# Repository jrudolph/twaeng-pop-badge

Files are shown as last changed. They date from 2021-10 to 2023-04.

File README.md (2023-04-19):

# Twäng POP! Badge

These are [KiCad](https://www.kicad.org/) sources from which the [Twäng](https://twaeng.de) [pop!](https://twaeng.de/musik/pop) badge was produced. This
is basically version 2 of the blinky sign described [on the blog](https://blog.virtual-void.net/2022/06/17/creating-a-blinky-sign-for-twaeng/).

The updated firmware can be built from the `pop-badge` branch of the [firmware repository](https://github.com/jrudolph/twaeng-pop-sign/tree/pop-badge).

## Schematics

The idea was to keep the basic original design based around a RPi Pico and WS2812b LEDs. For space and
cost reasons the amount of WS2812 LEDs was reduced to 25 and the smaller variant was chosen.

Additionally, 50 simple white LEDs were
added as a frame for the sign. These LEDs can not be controlled individually but only as the whole set. The brightness can be set by choosing appropriate PWM settings. 50 LEDs could consume 1A of
current which is a lot and cannot be sourced from a microcontroller pin directly. Since this was my first
electronics design, I was not totally certain how to set this up properly, so I went with a design, where I put both an NPN-transistor and an N-channel MOSFET on the board configurable via solder
jumpers. (It wasn't clear to me how much current the NPN transistor would really need to switch on all those 50 LEDs. The current gain might be enough to drive those but I wasn't sure what it would mean under PWM and under how much strain it would put the output pin of the Pico.)

I also put a debug header on the board for easy testing of components without requiring to
immediately solder the RPi Pico.

The Pico itself is soldered to the back using its castellated edges. The idea is here, to piggy-back
on the proven design of the Pico and avoid experimenting with a full-fledged MCU design. The Pico has a very flexible input power design based on a switching buck/boost converter, so you can either run via USB or any other power source like AA batteries within a wide range of voltages.

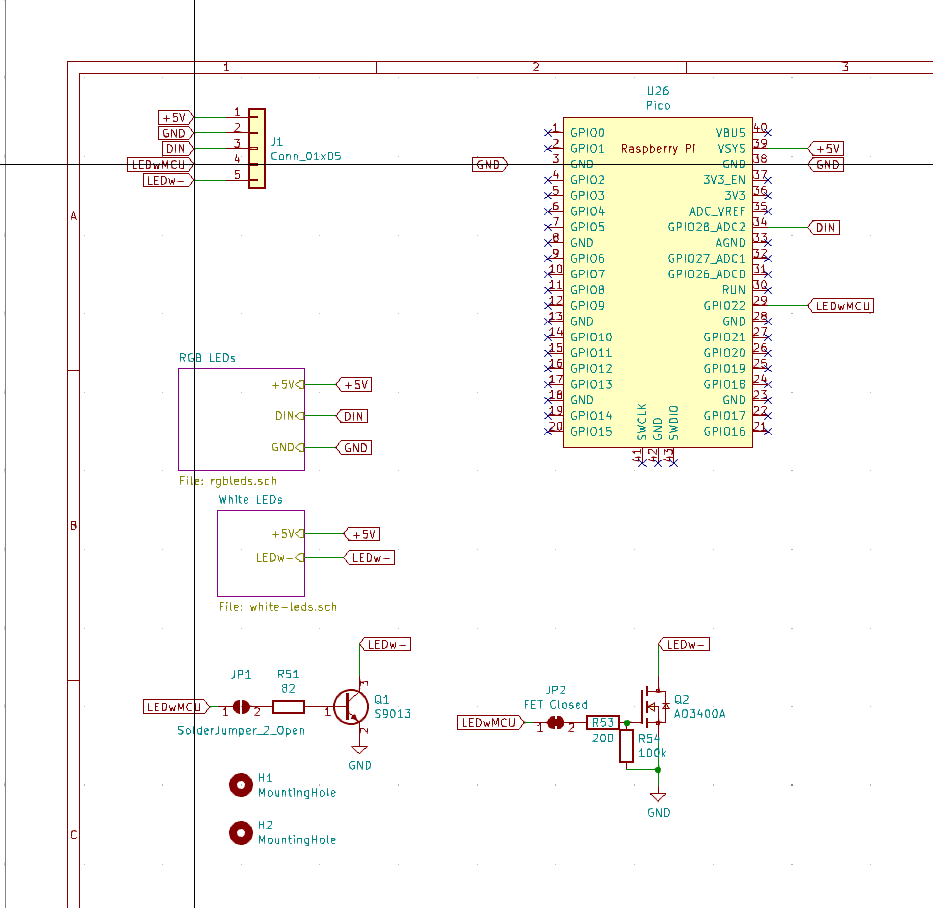
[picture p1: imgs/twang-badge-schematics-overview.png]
Overview


The LED setup is schematically simple:

RGB LEDs:

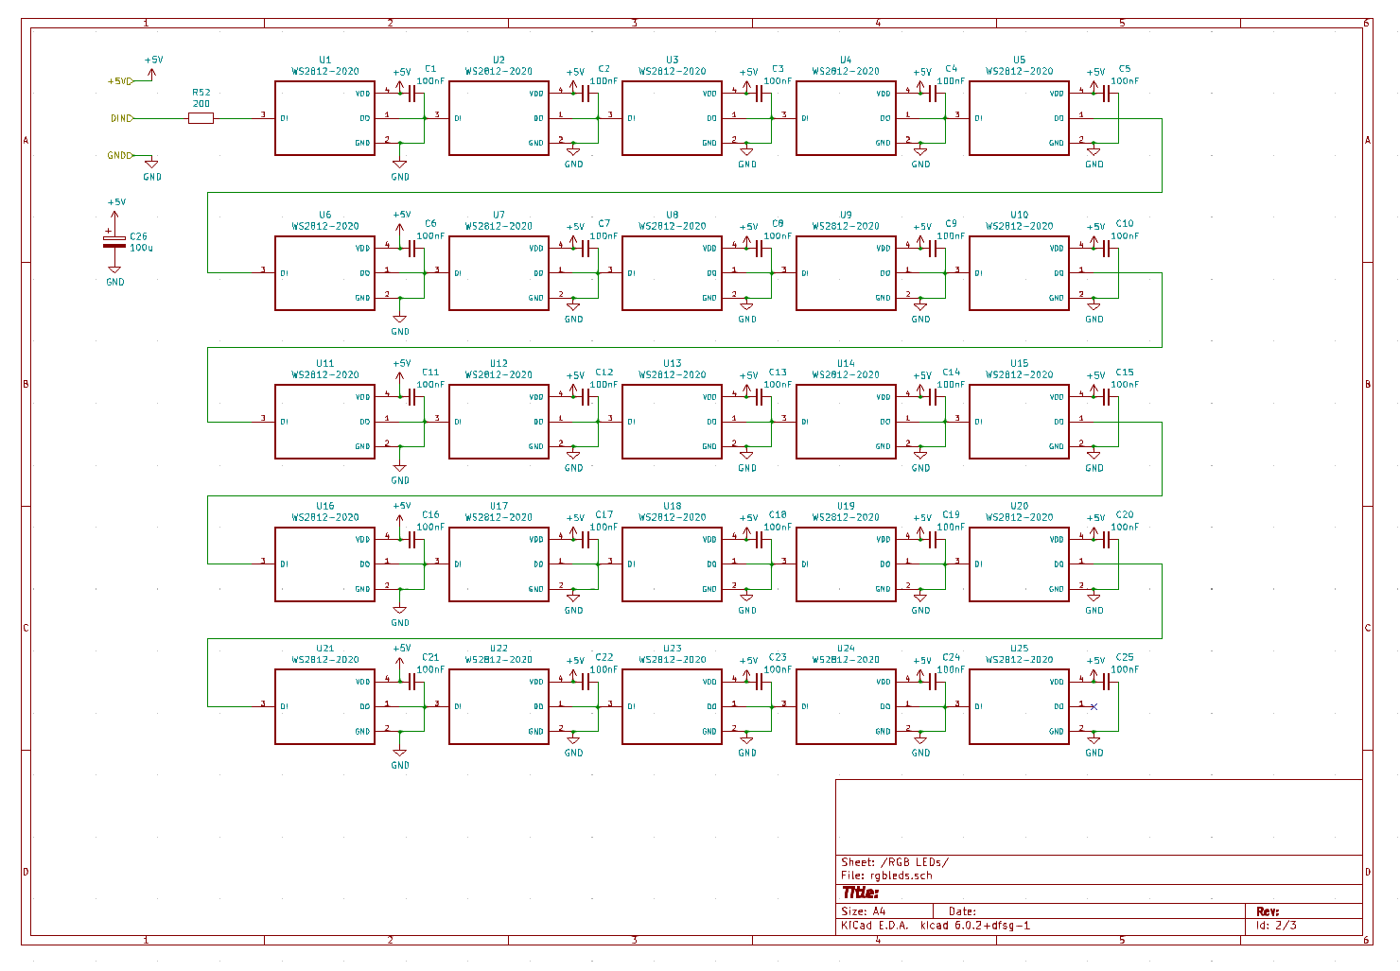
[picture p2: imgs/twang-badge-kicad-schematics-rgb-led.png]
WS2812B


White LEDs:

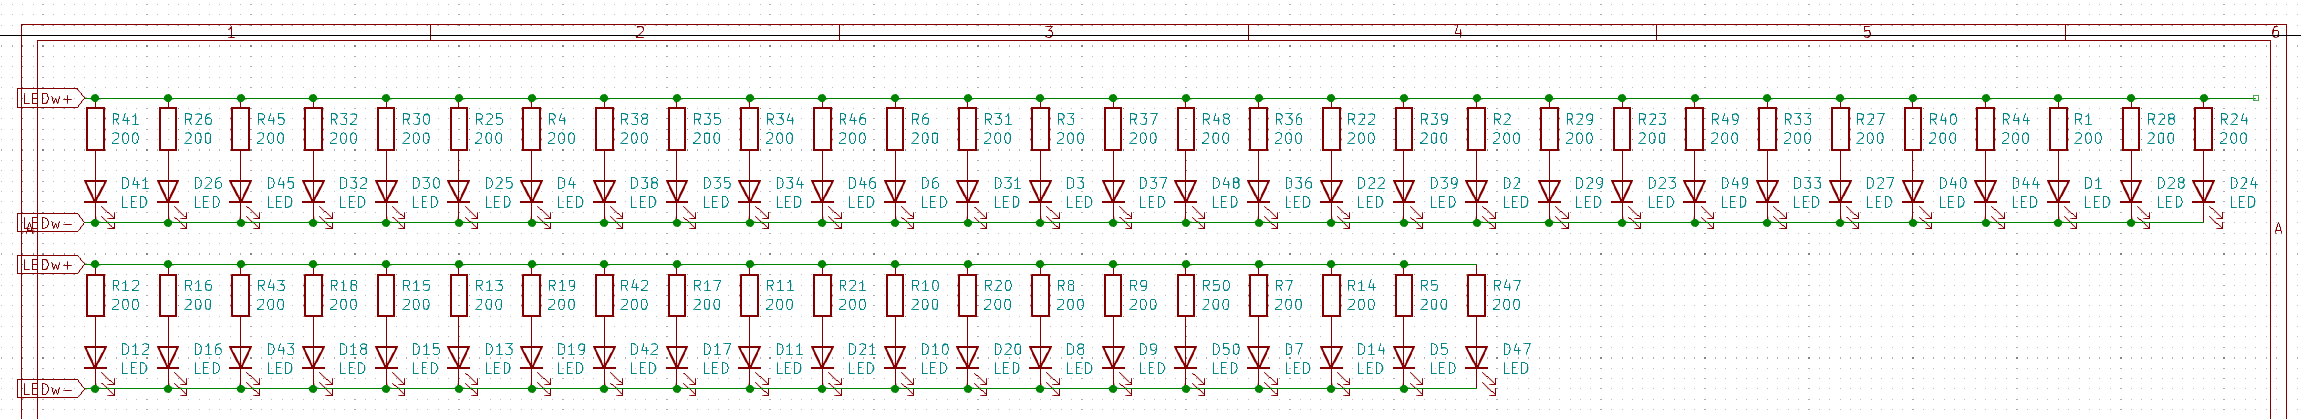
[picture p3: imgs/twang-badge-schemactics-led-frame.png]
WhiteLEDs


## PCB

The PCB has the outline of speech bubble in the form of a star. It uses a two layer design
with most of the back being the ground plane with a small amount of via connections.

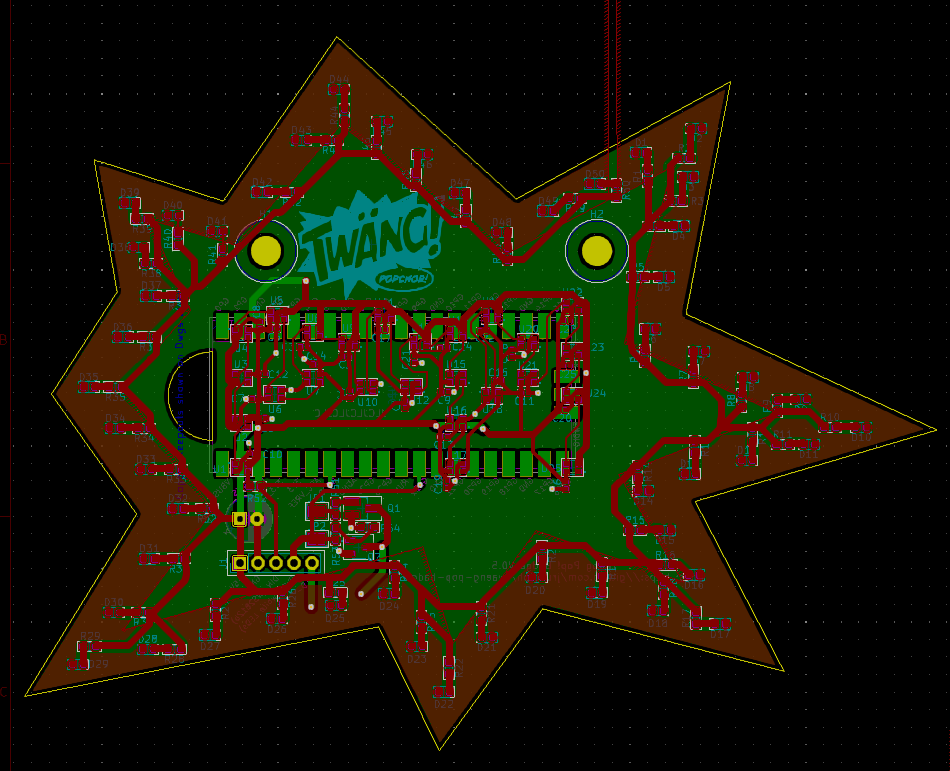
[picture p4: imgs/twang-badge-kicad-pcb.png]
PCB


On the front are all the LEDs with the required support components. The white LEDs are switched on the low-side (via the N-channel MOSFET), so the outer frame is a fill which goes to the source of the MOSFET. I read that having loops on a PCB will more likely act as an antenna, so I spared out a bit of the fill in the upper-right corner. The anode of the LEDs is directly connected to 5V. The MOSFET is controlled via a MCU pin, using PWM to dim the LEDs. They will never be driven with full power, which would use `50 x 20mA = 1A` (and would be even more blindingly bright).

Here's KiCad's 3D rendering of the front:

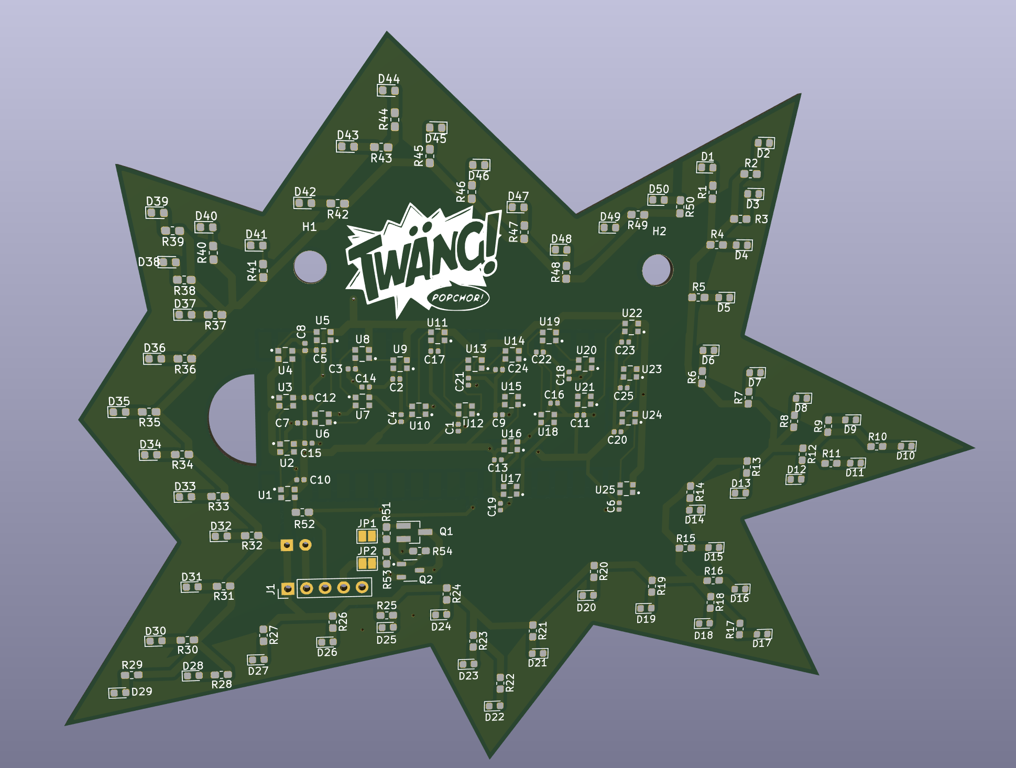
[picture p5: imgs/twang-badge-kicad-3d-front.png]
PCB Front


On the back there is room to solder the Pico itself to the board, and an electrolytic capacitor to relieve the power source (but it also works reliably without), so I didn't actually place them. I left a half-circle cutout where the USB port of the Pico would be to hopefully allow USB plugs to
fit in more easily. Unfortunately, the cutout is to small to accommodate all kinds of plugs. Some
plugs fit, some don't.

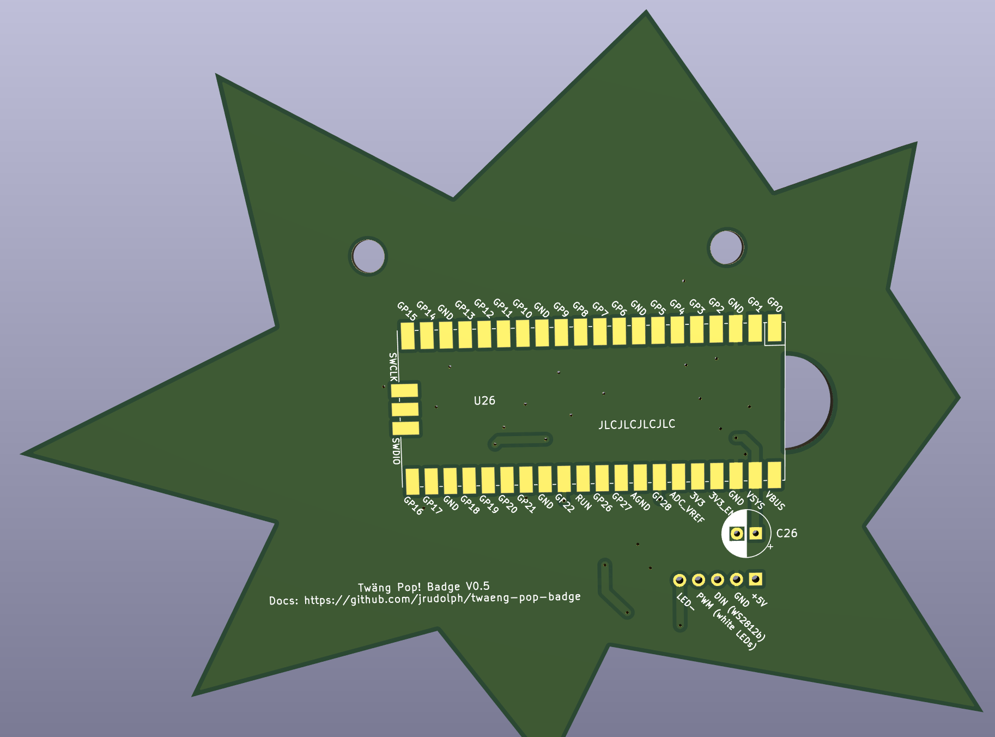
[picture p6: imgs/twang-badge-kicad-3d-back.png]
PCB Back


## Final Result

This is how the badges looked in their shiny black solder mask when I unpacked them after production.

Front:

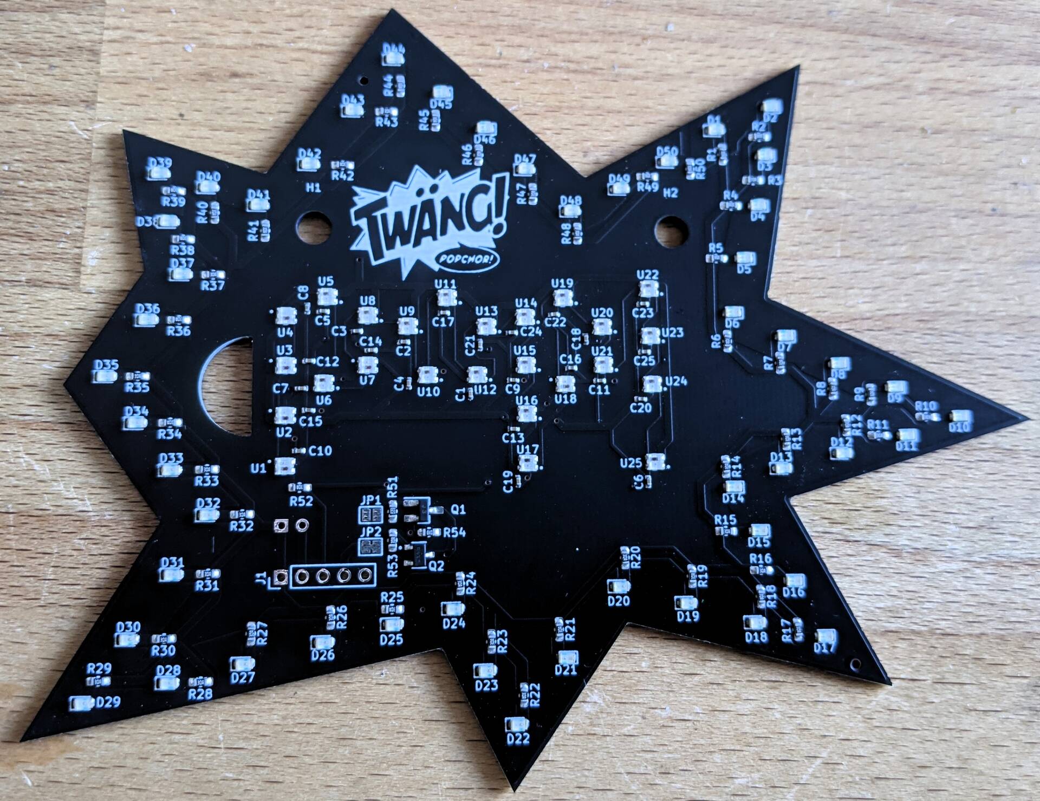
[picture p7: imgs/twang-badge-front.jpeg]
PCB Front Produced


Back:
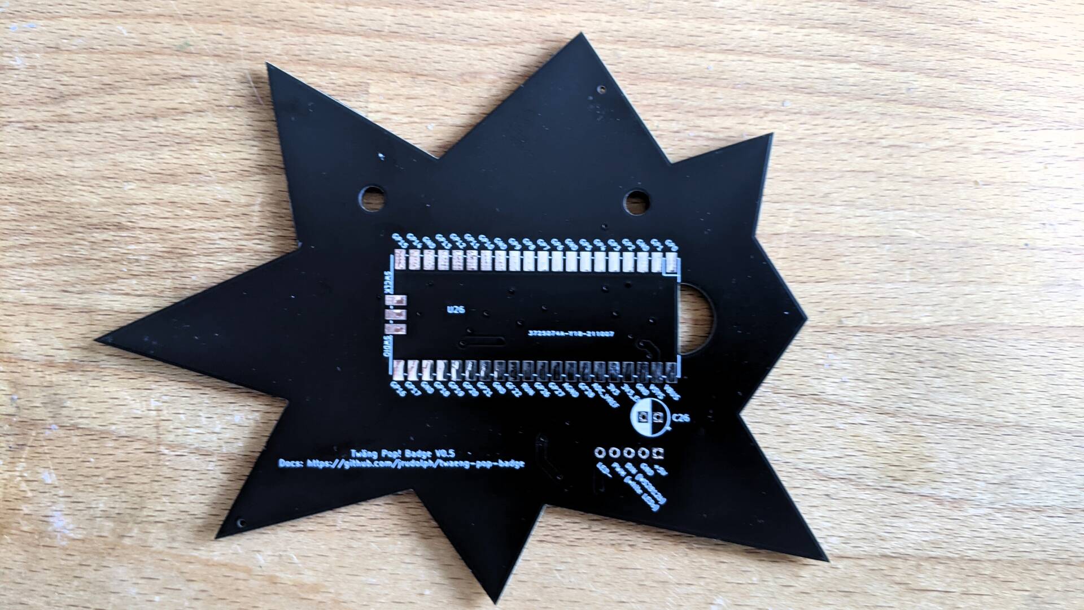
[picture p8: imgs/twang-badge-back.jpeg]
PCB Back Produced


A first test using after soldering the test headers showed an unexpected result:

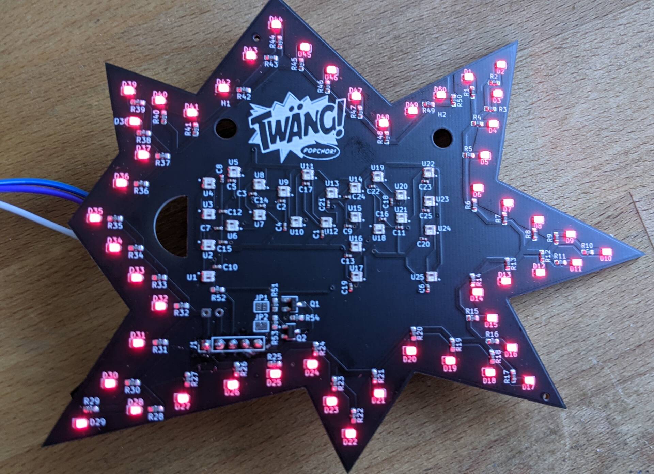
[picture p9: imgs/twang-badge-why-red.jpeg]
PCB Red Leds?


The outer frame of LEDs was red but I had ordered white LEDs instead (and also selected the
current limiting resistors based on the white LEDs' specs). After some back and forth, it turned
indeed out to be a production mistake. After quite some discussion, finally the production cost
was waived, I was happy about that even if the visual effect was not quite as intended.

After soldering the Pico to the back, I started [adapting the firmware](https://github.com/jrudolph/twaeng-pop-sign/compare/main...pop-badge) to the new layout. The number of
LEDs had to be adapted and I also created a new rainbow wave animation. This required to
know the position of the RGB LEDs, which [could be extracted](pop-badge/extract-pos.scala) from the placement files that
were needed for the production assembly.

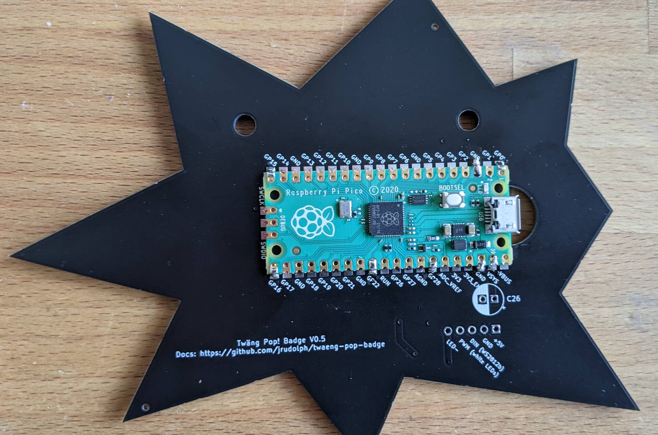
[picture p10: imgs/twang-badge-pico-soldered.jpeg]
PCB with Pico soldered on


and finally the new version came alive:

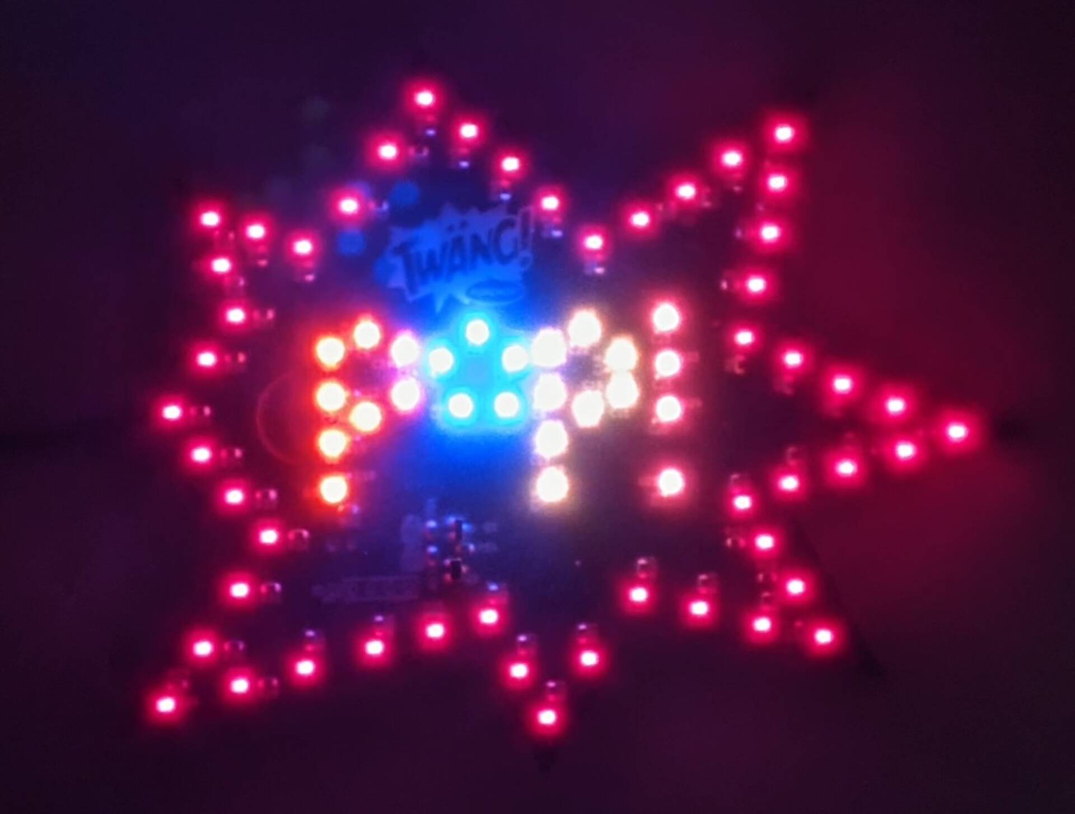
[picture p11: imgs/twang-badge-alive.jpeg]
PCB is alive


Here are old and new version next to each other:

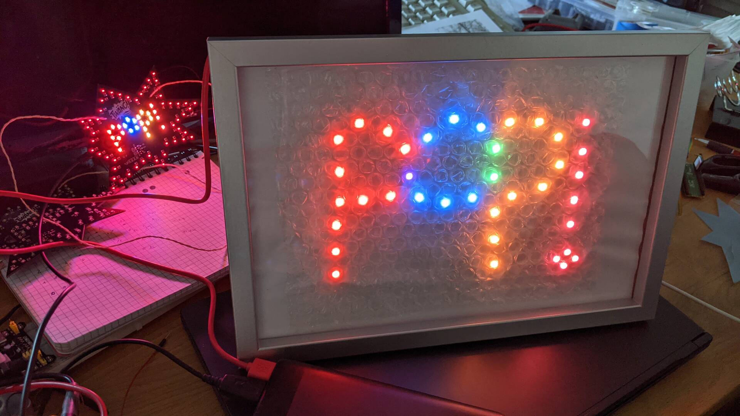
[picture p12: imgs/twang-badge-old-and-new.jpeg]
Blinky siblings


All of the LEDs are blindingly bright, so I experimented with different kinds of sheets to put in
front to diffuse the light a bit and take a bit away from the brightness. The final setup was placed in a small frame behind a sheet of diffusing paper and is now powered with 3 AA batteries (which is also safer than a solution powered by lithium batteries).

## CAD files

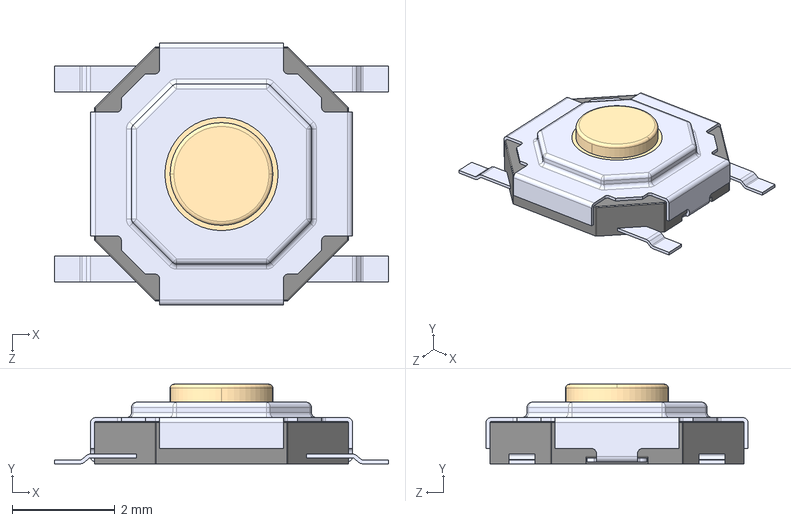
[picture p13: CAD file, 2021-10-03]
pop-badge/footprints/TS-1187A-B-A-B.step
6.50 x 1.55 x 5.10 mm

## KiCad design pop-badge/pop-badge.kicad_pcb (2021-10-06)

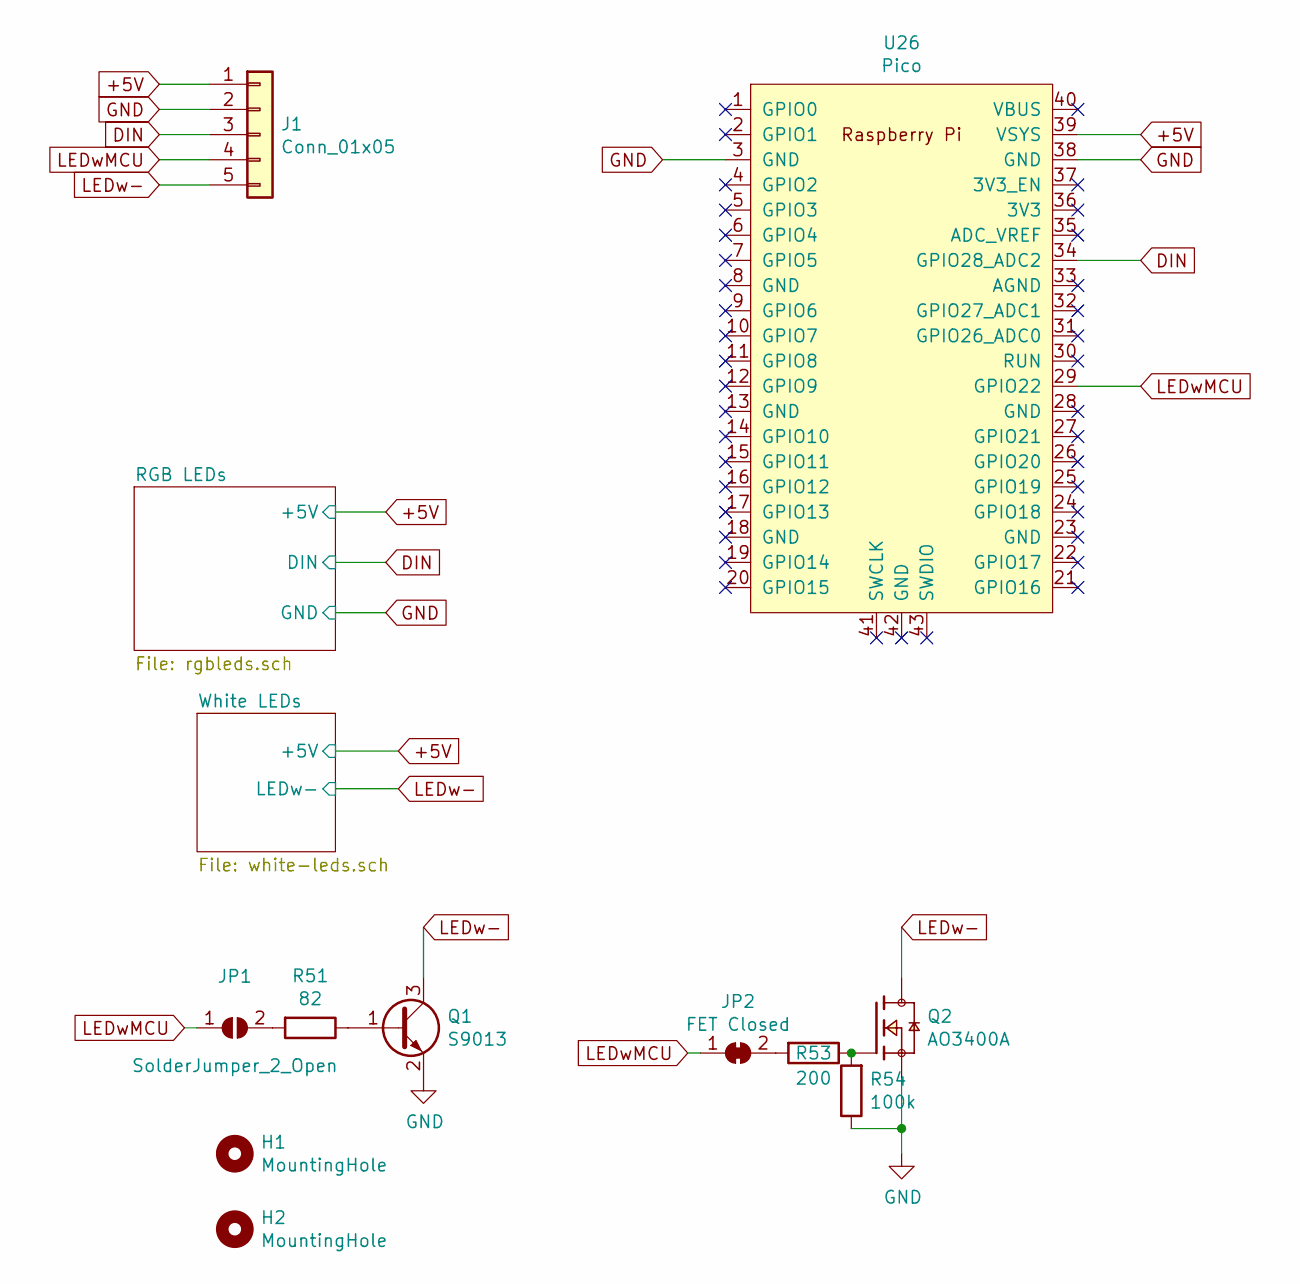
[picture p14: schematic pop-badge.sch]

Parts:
H1, H2: MountingHole; MountingHole_4.3mm_M4
J1: Conn_01x05; PinHeader_1x05_P2.54mm_Vertical
JP1: SolderJumper_2_Open; SolderJumper-2_P1.3mm_Open_Pad1.0x1.5mm
JP2: FET Closed; SolderJumper-2_P1.3mm_Bridged_Pad1.0x1.5mm
Q1: S9013; SOT-23_Handsoldering; JLC C6749
Q2: AO3400A; SOT95P280X125-3N; PARTREV L; JLC C20917
R51: 82; R_0603_1608Metric_Pad1.05x0.95mm_HandSolder; JLC 0603
R53: 200; R_0603_1608Metric_Pad1.05x0.95mm_HandSolder; JLC 0603
R54: 100k; R_0603_1608Metric_Pad1.05x0.95mm_HandSolder; JLC 0603
U26: Pico; RPi_Pico_SMD

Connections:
+5V: J1.1, U26.39 (VSYS); also elsewhere on the board
DIN: J1.3, U26.34 (GPIO28_ADC2); also elsewhere on the board
GND: J1.2, Q1.2 (E), Q2.2, R54.1, U26.3 (GND), U26.38 (GND); also elsewhere on the board
LEDw-: J1.5, Q1.3 (C), Q2.3; also elsewhere on the board
LEDwMCU: J1.4, JP1.1 (A), JP2.1 (A), U26.29 (GPIO22)
unnamed: JP1.2 (B), R51.2
unnamed: JP2.2 (B), R53.2
unnamed: Q1.1 (B), R51.1
unnamed: Q2.1, R53.1, R54.2

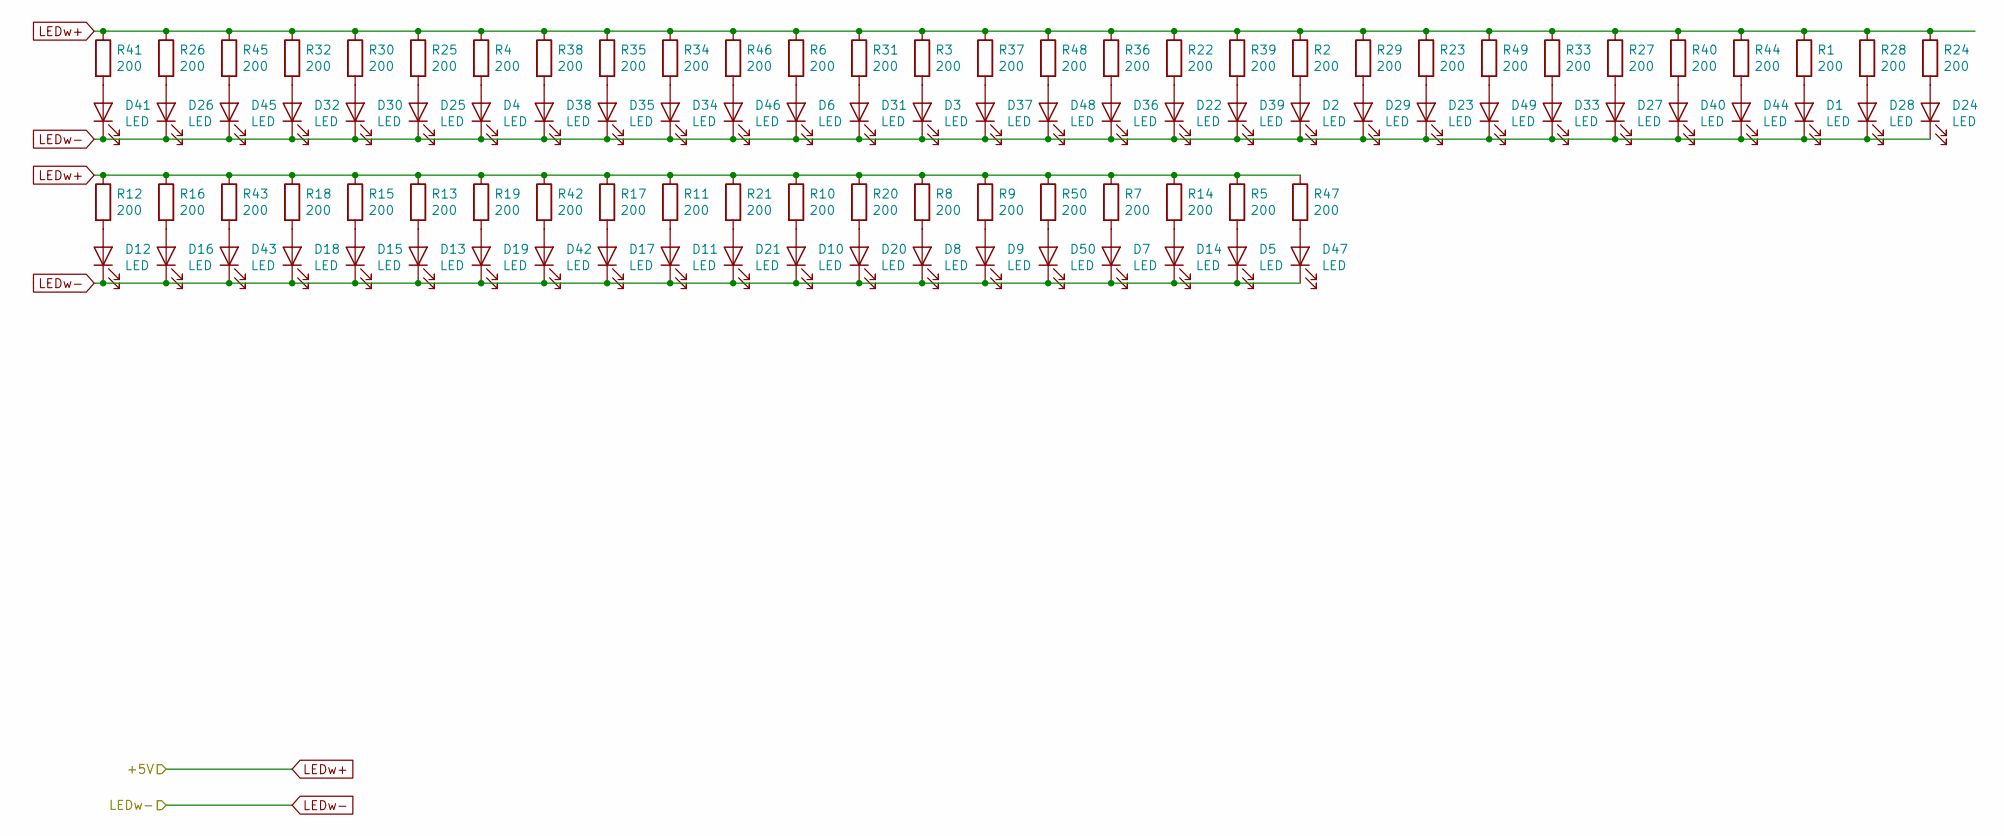
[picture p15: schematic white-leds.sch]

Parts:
D1, D2, D3, D4, D5, D6, D7, D8, D9, D10, D11, D12, D13, D14, D15, D16, D17, D18, D19, D20, D21, D22, D23, D24, D25, D26, D27, D28, D29, D30, D31, D32, D33, D34, D35, D36, D37, D38, D39, D40, D41, D42, D43, D44, D45, D46, D47, D48, D49, D50: LED; LED_0603_1608Metric; JLC C115461
R1, R2, R3, R4, R5, R6, R7, R8, R9, R10, R11, R12, R13, R14, R15, R16, R17, R18, R19, R20, R21, R22, R23, R24, R25, R26, R27, R28, R29, R30, R31, R32, R33, R34, R35, R36, R37, R38, R39, R40, R41, R42, R43, R44, R45, R46, R47, R48, R49, R50: 200; R_0603_1608Metric_Pad1.05x0.95mm_HandSolder; JLC 0603

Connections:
+5V: R1.1, R2.1, R3.1, R4.1, R5.1, R6.1, R7.1, R8.1, R9.1, R10.1, R11.1, R12.1, R13.1, R14.1, R15.1, R16.1, R17.1, R18.1, R19.1, R20.1, R21.1, R22.1, R23.1, R24.1, R25.1, R26.1, R27.1, R28.1, R29.1, R30.1, R31.1, R32.1, R33.1, R34.1, R35.1, R36.1, R37.1, R38.1, R39.1, R40.1, R41.1, R42.1, R43.1, R44.1, R45.1, R46.1, R47.1, R48.1, R49.1, R50.1; also elsewhere on the board
LEDw-: D1.1 (K), D2.1 (K), D3.1 (K), D4.1 (K), D5.1 (K), D6.1 (K), D7.1 (K), D8.1 (K), D9.1 (K), D10.1 (K), D11.1 (K), D12.1 (K), D13.1 (K), D14.1 (K), D15.1 (K), D16.1 (K), D17.1 (K), D18.1 (K), D19.1 (K), D20.1 (K), D21.1 (K), D22.1 (K), D23.1 (K), D24.1 (K), D25.1 (K), D26.1 (K), D27.1 (K), D28.1 (K), D29.1 (K), D30.1 (K), D31.1 (K), D32.1 (K), D33.1 (K), D34.1 (K), D35.1 (K), D36.1 (K), D37.1 (K), D38.1 (K), D39.1 (K), D40.1 (K), D41.1 (K), D42.1 (K), D43.1 (K), D44.1 (K), D45.1 (K), D46.1 (K), D47.1 (K), D48.1 (K), D49.1 (K), D50.1 (K); also elsewhere on the board
unnamed: D1.2 (A), R1.2
unnamed: D2.2 (A), R2.2
unnamed: D3.2 (A), R3.2
unnamed: D4.2 (A), R4.2
unnamed: D5.2 (A), R5.2
unnamed: D6.2 (A), R6.2
unnamed: D7.2 (A), R7.2
unnamed: D8.2 (A), R8.2
unnamed: D9.2 (A), R9.2
unnamed: D10.2 (A), R10.2
unnamed: D11.2 (A), R11.2
unnamed: D12.2 (A), R12.2
unnamed: D13.2 (A), R13.2
unnamed: D14.2 (A), R14.2
unnamed: D15.2 (A), R15.2
unnamed: D16.2 (A), R16.2
unnamed: D17.2 (A), R17.2
unnamed: D18.2 (A), R18.2
unnamed: D19.2 (A), R19.2
unnamed: D20.2 (A), R20.2
unnamed: D21.2 (A), R21.2
unnamed: D22.2 (A), R22.2
unnamed: D23.2 (A), R23.2
unnamed: D24.2 (A), R24.2
unnamed: D25.2 (A), R25.2
unnamed: D26.2 (A), R26.2
unnamed: D27.2 (A), R27.2
unnamed: D28.2 (A), R28.2
unnamed: D29.2 (A), R29.2
unnamed: D30.2 (A), R30.2
unnamed: D31.2 (A), R31.2
unnamed: D32.2 (A), R32.2
unnamed: D33.2 (A), R33.2
unnamed: D34.2 (A), R34.2
unnamed: D35.2 (A), R35.2
unnamed: D36.2 (A), R36.2
unnamed: D37.2 (A), R37.2
unnamed: D38.2 (A), R38.2
unnamed: D39.2 (A), R39.2
unnamed: D40.2 (A), R40.2
unnamed: D41.2 (A), R41.2
unnamed: D42.2 (A), R42.2
unnamed: D43.2 (A), R43.2
unnamed: D44.2 (A), R44.2
unnamed: D45.2 (A), R45.2
unnamed: D46.2 (A), R46.2
unnamed: D47.2 (A), R47.2
unnamed: D48.2 (A), R48.2
unnamed: D49.2 (A), R49.2
unnamed: D50.2 (A), R50.2

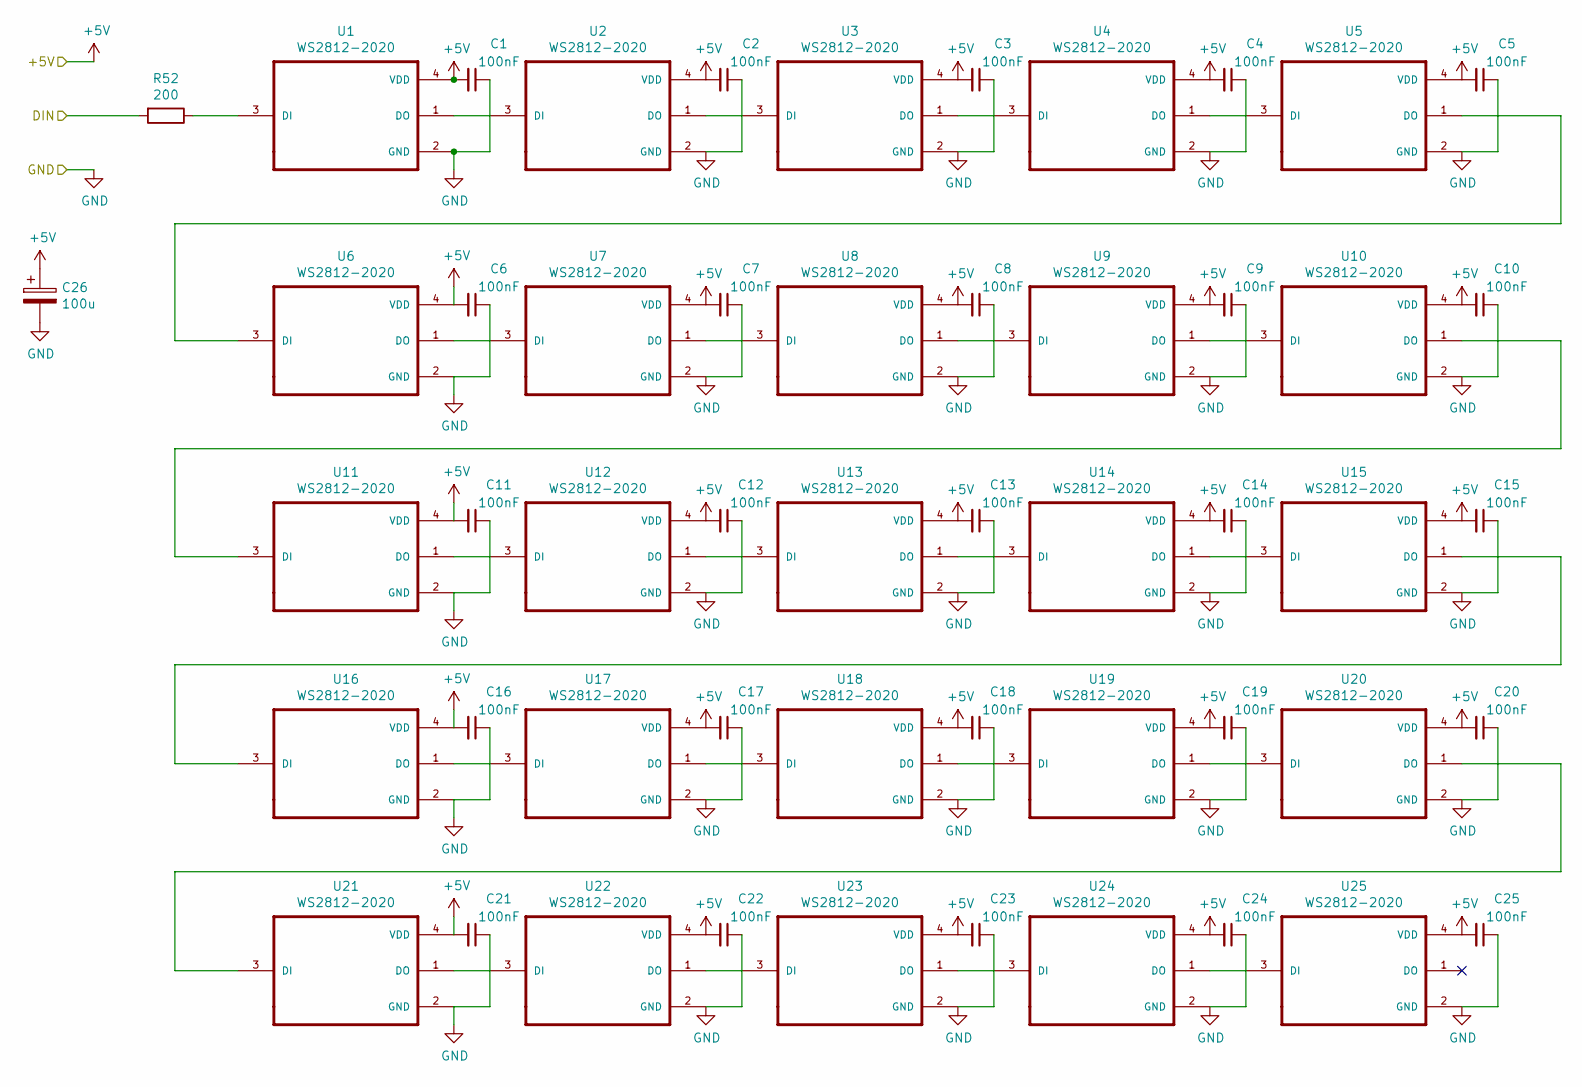
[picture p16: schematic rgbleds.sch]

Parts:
C1, C2, C3, C4, C5, C6, C7, C8, C9, C10, C11, C12, C13, C14, C15, C16, C17, C18, C19, C20, C21, C22, C23, C24, C25: 100nF; C_0402_1005Metric; JLC 0402
C26: 100u; CP_Radial_D6.3mm_P2.50mm
R52: 200; R_0603_1608Metric_Pad1.05x0.95mm_HandSolder; JLC 0603
U1, U2, U3, U4, U5, U6, U7, U8, U9, U10, U11, U12, U13, U14, U15, U16, U17, U18, U19, U20, U21, U22, U23, U24, U25: WS2812-2020; LED_WS2812-2020; JLC C965555

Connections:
+5V: C1.2, C2.2, C3.2, C4.2, C5.2, C6.2, C7.2, C8.2, C9.2, C10.2, C11.2, C12.2, C13.2, C14.2, C15.2, C16.2, C17.2, C18.2, C19.2, C20.2, C21.2, C22.2, C23.2, C24.2, C25.2, C26.1, U1.4 (VDD), U2.4 (VDD), U3.4 (VDD), U4.4 (VDD), U5.4 (VDD), U6.4 (VDD), U7.4 (VDD), U8.4 (VDD), U9.4 (VDD), U10.4 (VDD), U11.4 (VDD), U12.4 (VDD), U13.4 (VDD), U14.4 (VDD), U15.4 (VDD), U16.4 (VDD), U17.4 (VDD), U18.4 (VDD), U19.4 (VDD), U20.4 (VDD), U21.4 (VDD), U22.4 (VDD), U23.4 (VDD), U24.4 (VDD), U25.4 (VDD); also elsewhere on the board
DIN: R52.2; also elsewhere on the board
GND: C1.1, C2.1, C3.1, C4.1, C5.1, C6.1, C7.1, C8.1, C9.1, C10.1, C11.1, C12.1, C13.1, C14.1, C15.1, C16.1, C17.1, C18.1, C19.1, C20.1, C21.1, C22.1, C23.1, C24.1, C25.1, C26.2, U1.2 (GND), U2.2 (GND), U3.2 (GND), U4.2 (GND), U5.2 (GND), U6.2 (GND), U7.2 (GND), U8.2 (GND), U9.2 (GND), U10.2 (GND), U11.2 (GND), U12.2 (GND), U13.2 (GND), U14.2 (GND), U15.2 (GND), U16.2 (GND), U17.2 (GND), U18.2 (GND), U19.2 (GND), U20.2 (GND), U21.2 (GND), U22.2 (GND), U23.2 (GND), U24.2 (GND), U25.2 (GND); also elsewhere on the board
unnamed: R52.1, U1.3 (DI)
unnamed: U1.1 (DO), U2.3 (DI)
unnamed: U2.1 (DO), U3.3 (DI)
unnamed: U3.1 (DO), U4.3 (DI)
unnamed: U4.1 (DO), U5.3 (DI)
unnamed: U5.1 (DO), U6.3 (DI)
unnamed: U6.1 (DO), U7.3 (DI)
unnamed: U7.1 (DO), U8.3 (DI)
unnamed: U8.1 (DO), U9.3 (DI)
unnamed: U10.1 (DO), U11.3 (DI)
unnamed: U9.1 (DO), U10.3 (DI)
unnamed: U11.1 (DO), U12.3 (DI)
unnamed: U12.1 (DO), U13.3 (DI)
unnamed: U13.1 (DO), U14.3 (DI)
unnamed: U14.1 (DO), U15.3 (DI)
unnamed: U15.1 (DO), U16.3 (DI)
unnamed: U16.1 (DO), U17.3 (DI)
unnamed: U17.1 (DO), U18.3 (DI)
unnamed: U18.1 (DO), U19.3 (DI)
unnamed: U19.1 (DO), U20.3 (DI)
unnamed: U20.1 (DO), U21.3 (DI)
unnamed: U21.1 (DO), U22.3 (DI)
unnamed: U22.1 (DO), U23.3 (DI)
unnamed: U23.1 (DO), U24.3 (DI)
unnamed: U24.1 (DO), U25.3 (DI)

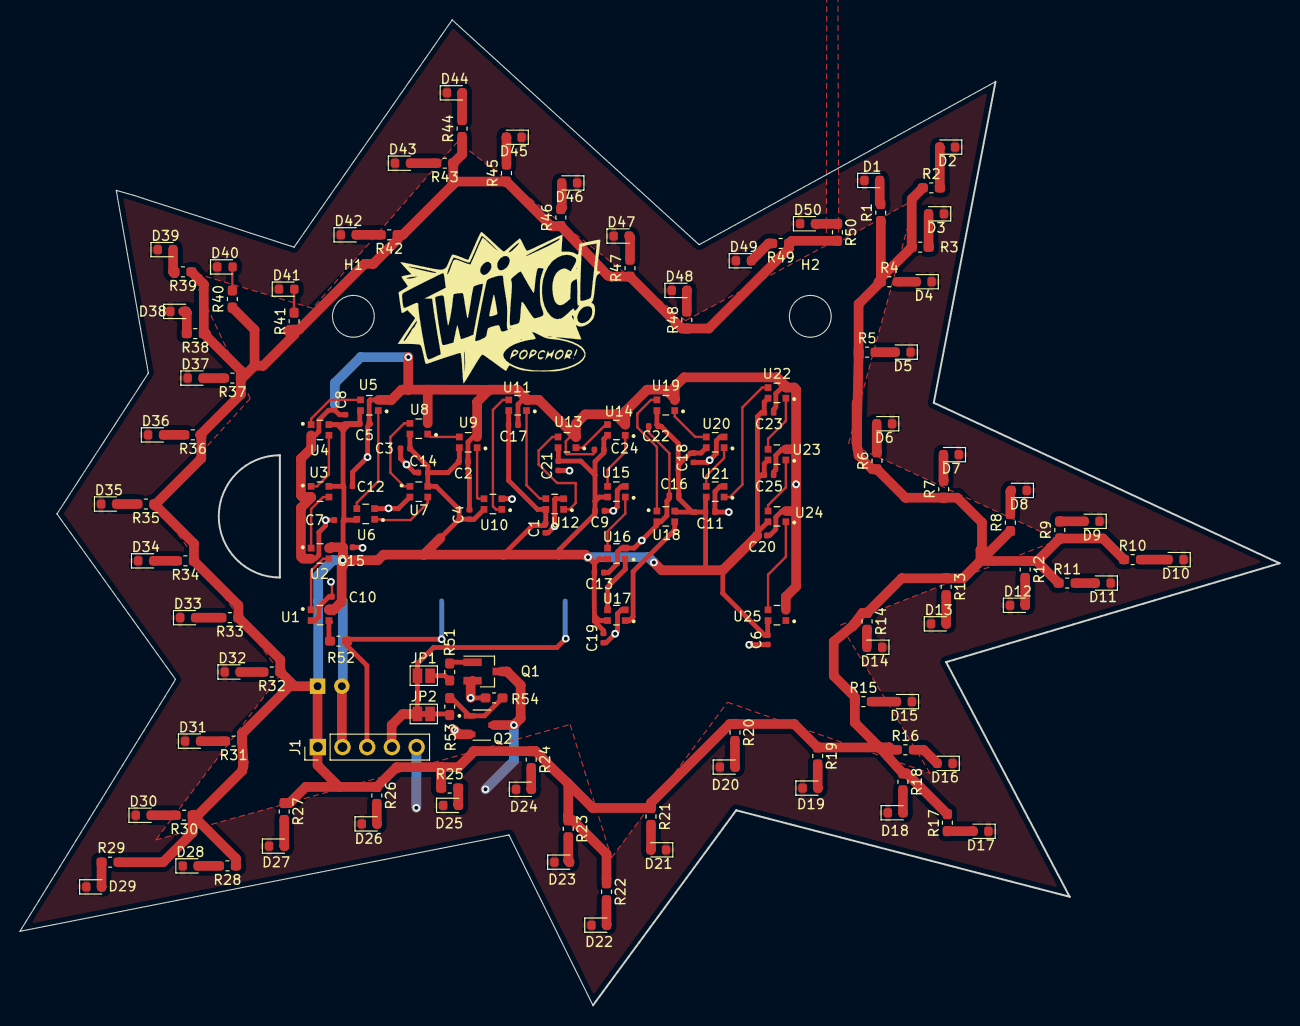
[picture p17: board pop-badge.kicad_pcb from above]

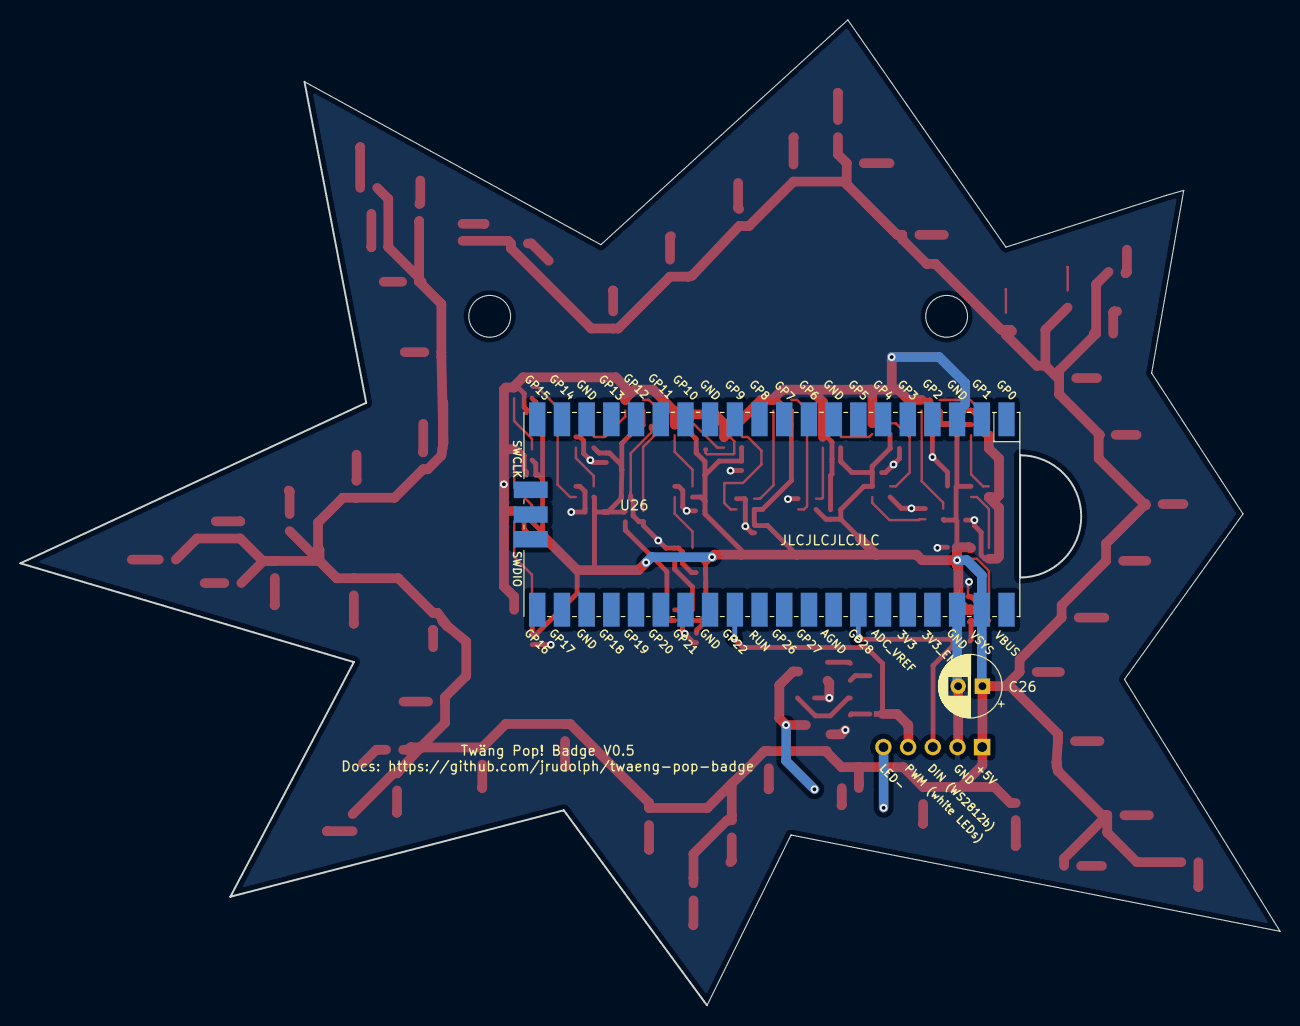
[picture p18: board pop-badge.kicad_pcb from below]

Board: 2 copper layers, 129.5 x 101.3 mm, 163 parts (2 on the bottom side), 84 nets.

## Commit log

2021-09-29 initial version
    [pop-badge.kicad_pcb, pop-badge.sch, rgbleds.sch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]
2021-09-29 much more layouting
    [pop-badge.kicad_pcb, pop-badge.sch, rgbleds.sch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]
2021-09-29 routing mostly done
    [pop-badge.kicad_pcb, rgbleds.sch, white-leds.sch]
2021-09-30 current state
    [pop-badge.kicad_pcb]
2021-09-30 add WS2812B 2020 decoupling caps (100nF)
    [rgbleds.sch]
2021-09-30 annotate decoupling caps
    [rgbleds.sch]
2021-09-30 add decoupling cap footprints
    [rgbleds.sch]
2021-09-30 import decoupling caps and remove power lines for redo for ws2812
    [pop-badge.kicad_pcb]
2021-09-30 routing done
    [pop-badge.kicad_pcb, pop-badge.sch, rgbleds.sch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]
2021-10-01 different BJT again
    [pop-badge.kicad_pcb, white-leds.sch]
2021-10-01 add a cut out for the usb connector
    [pop-badge.kicad_pcb]
2021-10-01 fix silk screen labels
    [pop-badge.kicad_pcb]
2021-10-01 fix cut out vs traces
    [pop-badge.kicad_pcb]
2021-10-01 silk screen fix
    [pop-badge.kicad_pcb]
2021-10-01 small bom fixes
    [rgbleds.sch]
2021-10-01 use 200 ohm current limiting resistor for LED
    To have more headroom without bringing BJT to its limits.
    Calculation basis:
    V_CE 0.6V max
    LTW-C193SN5 10mA at 3.15V, from chart ~ 5mA at 3V
    7mA at 200 Ohm = 1.4V voltage drop
    worst case 5V - 0.5V - 1.4V = 3.1V ~ 7mA at LED according to LED IV chart
    [pop-badge.kicad_pcb, white-leds.sch]
2021-10-01 redo power rails to avoid loops
    [pop-badge.kicad_pcb, pop-badge.sch]
2021-10-01 some silkscreen adjustments
    [pop-badge.kicad_pcb]
2021-10-02 use proper pin connector and expose LEDw- on connector
    [pop-badge.kicad_pcb, pop-badge.sch, white-leds.sch]
2021-10-02 add twaeng sign
    [pop-badge.kicad_pcb]
2021-10-02 add alternative path
    [pop-badge.kicad_pcb, pop-badge.sch, rgbleds.sch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]
2021-10-02 add pull down for mosfet
    [pop-badge.kicad_pcb, pop-badge.sch]
2021-10-02 slight tracking changes
    [pop-badge.kicad_pcb]
2021-10-03 add button
    [TS-1187A-B-A-B.step, pop-badge.kicad_pcb, pop-badge.sch]
2021-10-04 some cosmetic changes
    [pop-badge.kicad_pcb, pop-badge.sch]
2021-10-04 remove button again
    [pop-badge.kicad_pcb, pop-badge.sch]
2021-10-04 add rescue lib
    [pop-badge.sch, rgbleds.sch]
2021-10-06 change footprint for npn slightly
    [pop-badge.kicad_pcb, pop-badge.sch]
2021-10-06 remove button label
    [pop-badge.kicad_pcb]
2021-10-06 renumber white leds
    [pop-badge.kicad_pcb, white-leds.sch]
2021-10-06 set smd attribute for ws2812bs
    [pop-badge.kicad_pcb]
2021-11-17 script to extract positions of WS2812B LEDs from placement files
